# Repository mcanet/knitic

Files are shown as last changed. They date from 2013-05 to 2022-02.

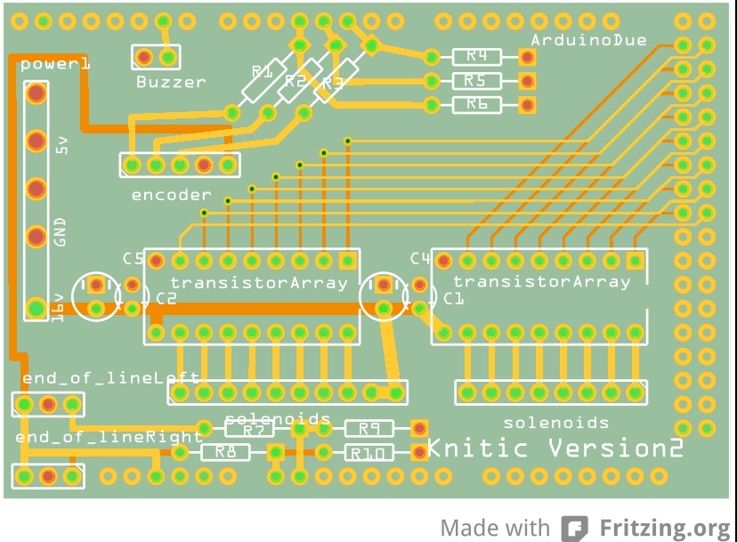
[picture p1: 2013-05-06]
pcb_design/ArduinoDue/KniticV2_+CompactPCB2Res_pcb.jpg

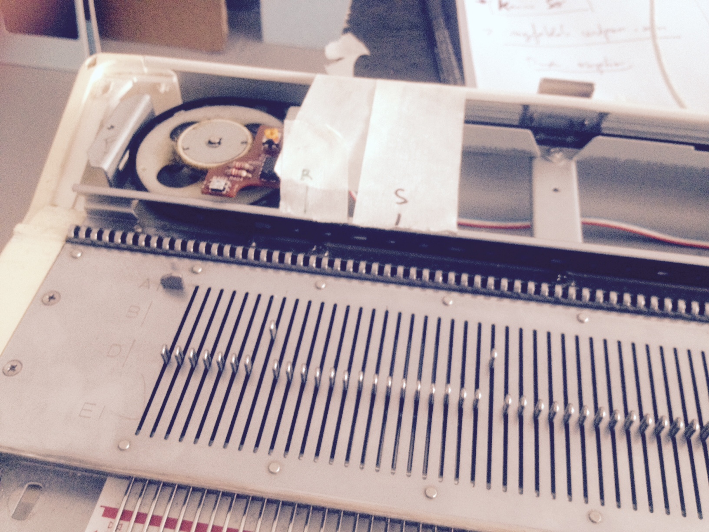
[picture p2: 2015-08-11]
arduino_code/test_incase_error/test_encoder_beltshift/regular.jpg

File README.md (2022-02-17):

Knitic
======

This software is part of the first open hardware knitting machine project, at the moment based on old electronic Brother knitting machines. 

Here we are testing with KH930, KH940, but we will work with any Digital Brother Knitting machine. 

We have developed in an artist residency at Marginalia+Lab in Belo Horizonte (Brazil) and Constant(Belgium). 
There is more information on the project website: http://knitic.com

Authors: Varvara Guljajeva(http://varvarag.info) and Mar Canet (http://mcanet.info). We are a couple of new media artist that we like to build our own tools.

We have publish some articles about this topic:
- Knitic - The Revolution of Soft Digital Fabrication. DH 2013: 497-499 [http://dh2013.unl.edu/abstracts/ab-173.html]

The project copyright with GNU-GPL: http://es.wikipedia.org/wiki/GNU_General_Public_License

Any questions please send to: mar.canet@gmail.com

> THIS MATERIAL IS DISTRIBUTED AS IS WITH NO GUARANTEE OF FUNCTIONALITY OR RELEVANCE TO THIRD PARTY PROJECTS - THE DEVELOPERS ARE THUS NOT TO BE HELD RESPONSIBLE FOR PERSONAL INJURIES, HARDWARE, FINANCIAL, OR ANY OTHER LOSSES AND IN GENERAL FOR ANY MISFORTUNATE EVENT CAUSED BY THE DESCRIBED SOFTWARE/HARDWARE OR IN THE PROCESS OF ATTEMPTING TO IMPLEMENT IT. IF YOU DON'T AGREE WITH THE AFOREMENTIONED YOUR ARE NOT ALLOWED TO USE THE MATERIAL PROVIDED HEREIN

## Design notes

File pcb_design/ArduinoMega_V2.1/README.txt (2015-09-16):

README Knitic v2.1 - 09/2015
Fablab Wellington
Zoilo ABAD

Changes :
-Eagle files
-improvement with smd component
-selectable 5V or 3.3V
-inboard resistor for optoswitch

-add a adapter board for KH-970 connector

choice the right resistor for the optoswitch you have and the voltage you have.

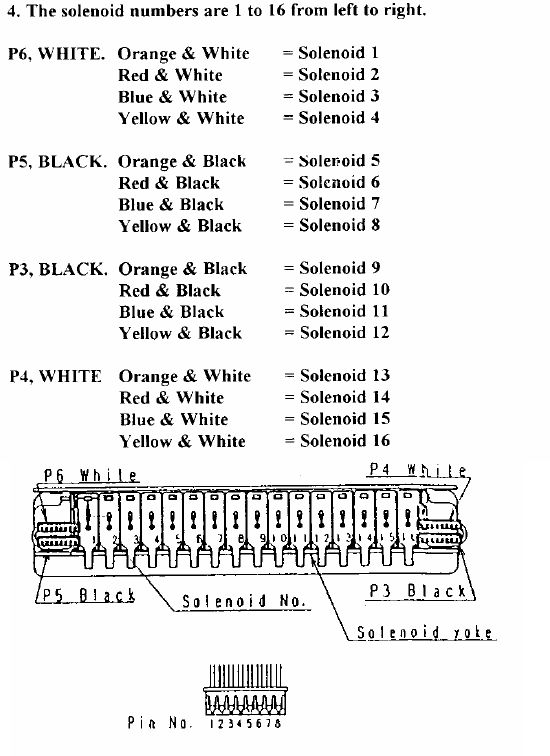
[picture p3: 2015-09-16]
pcb_design/ArduinoMega_V2.1/solenoids.png

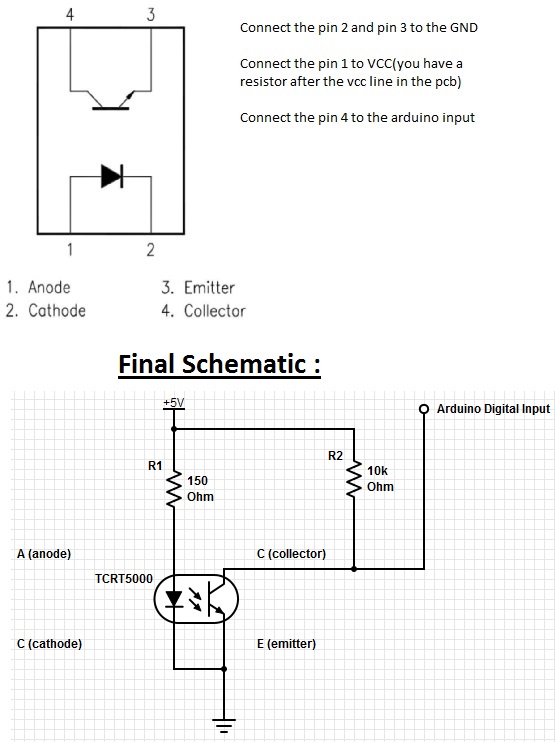
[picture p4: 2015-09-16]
pcb_design/ArduinoMega_V2.1/Opto switch.jpg

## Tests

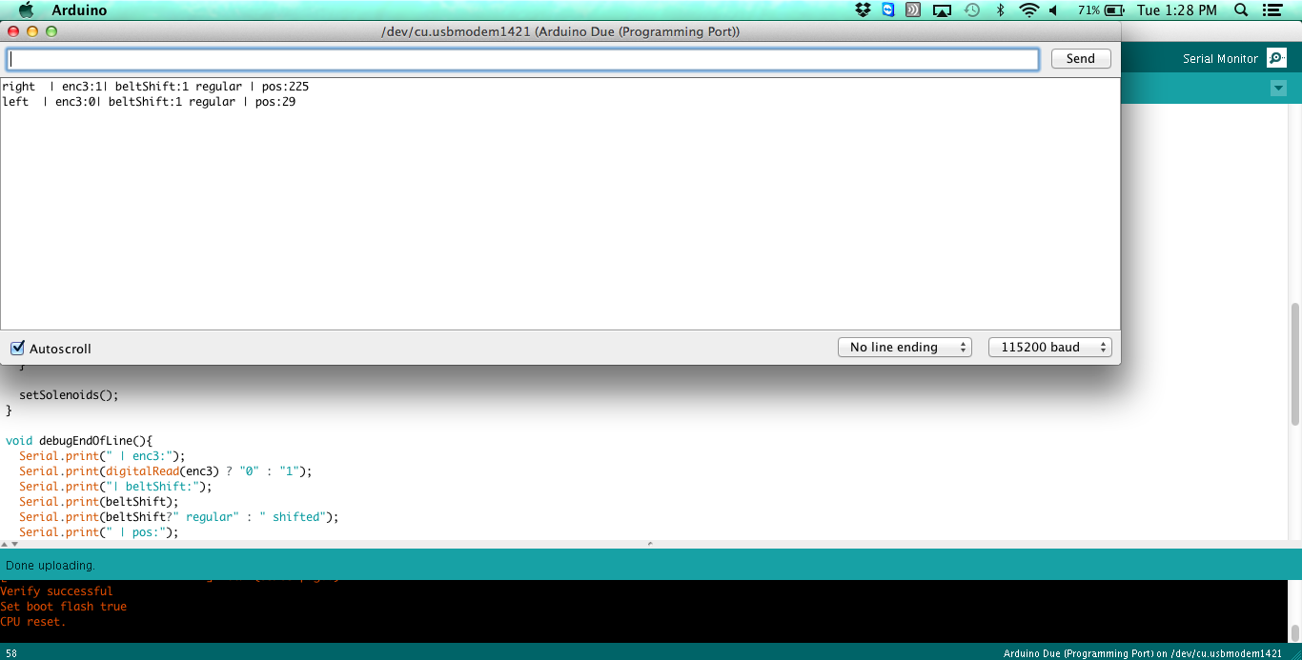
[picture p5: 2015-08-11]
arduino_code/test_incase_error/test_encoder_beltshift/console_showing_belt_status.png

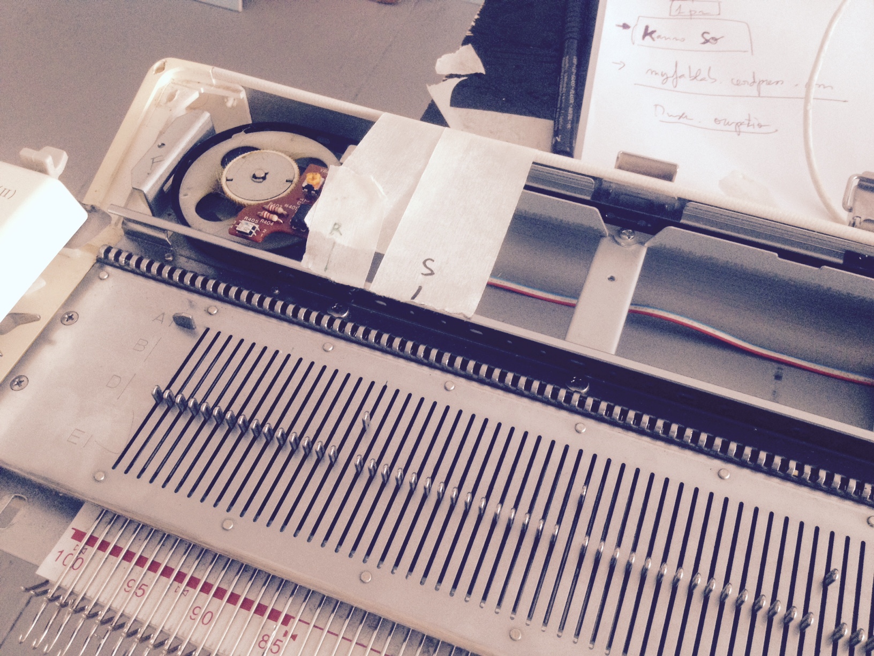
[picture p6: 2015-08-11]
arduino_code/test_incase_error/test_encoder_beltshift/shifted.jpg

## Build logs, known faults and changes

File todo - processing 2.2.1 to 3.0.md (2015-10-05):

todo

- sdrop doesn't work
- icon of standalone application doesn't work
- shape of parametric sweater doesn't work
- open and save dialogue close the main frame, know issue without solution yet (https://github.com/processing/processing/issues/3831)

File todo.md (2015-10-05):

todo

- fix "error in pixel" -> OK
- fix corrupt data that stop the arduino -> OK
- check solenoid glitch -> close to be OK, much better with the fork of kinasmith
- check beltshift
- begin message to less error -> ok
- release solenoid when no connection -> ok
- fast read write on arduino
- go to processing 3.0 (maybe delete the sdrop)

ayab
- initialisation
- active needle or not
- offset
- reset at the EOL

// Machine is initialized when left hall sensor is passed in Right direction
		if( Right == m_direction && Left == m_hallActive )
		{
			m_opState = s_ready;
			m_solenoids.setSolenoids(0xFFFF);
			return;
		}
		
if( (m_pixelToSet >= m_startNeedle-END_OF_LINE_OFFSET_L)
				&& (m_pixelToSet <= m_stopNeedle+END_OF_LINE_OFFSET_R)) // TODO ADD OFFSET
		{	// When inside the active needles
		}
		else
		{	// Outside of the active needles

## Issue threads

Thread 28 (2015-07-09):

Mac OS X not working

bamundy, 2015-07-09:
I'm using a MacBookPro 2.7GHz Intel Core i7 8Gb 1333 MHz DDR3 RAM using OS X 10.9.5. with an Arduino compatible OSEPP Uno R3 Plus.

I've downloaded the Arduino Application and am able to connect and power the board.

I've downloaded the latest Knitic software version from Github, yet every time I've attempted to open/install the software it gives the following error message . . . Please help.

Jo Ann Mundy

Arduino: 1.6.5 (Mac OS X), Board: "Arduino Uno"

protoAppKnitic_p5:11: error: variable or field 'serialEvent' declared void
protoAppKnitic_p5:11: error: expected ')' before 'p'
protoAppKnitic_p5:17: error: variable or field 'dropEvent' declared void
protoAppKnitic_p5:17: error: 'DropEvent' was not declared in this scope
protoAppKnitic_p5:8: error: 'import' does not name a type
protoAppKnitic_p5:9: error: 'import' does not name a type
protoAppKnitic_p5:10: error: 'import' does not name a type
protoAppKnitic_p5:11: error: 'import' does not name a type
protoAppKnitic_p5:12: error: 'import' does not name a type
protoAppKnitic_p5:13: error: 'import' does not name a type
protoAppKnitic_p5:17: error: 'ControlP5' does not name a type
protoAppKnitic_p5:18: error: 'Serial' does not name a type
protoAppKnitic_p5:19: error: 'PImage' does not name a type
protoAppKnitic_p5:20: error: 'PImage' does not name a type
protoAppKnitic_p5:21: error: 'PFont' does not name a type
protoAppKnitic_p5:29: error: expected unqualified-id before '[' token
protoAppKnitic_p5:39: error: expected unqualified-id before '[' token
protoAppKnitic_p5:40: error: expected unqualified-id before '[' token
protoAppKnitic_p5:70: error: storage size of 'bitRegister16SolenoidTemp' isn't known
protoAppKnitic_p5:71: error: 'SDrop' does not name a type
protoAppKnitic_p5:77: error: expected unqualified-id before '[' token
protoAppKnitic_p5:78: error: expected unqualified-id before '[' token
protoAppKnitic_p5:80: error: 'DropdownList' does not name a type
protoAppKnitic_p5:81: error: 'DropdownList' does not name a type
protoAppKnitic_p5:82: error: 'JSONObject' does not name a type
protoAppKnitic_p5:83: error: 'parametricSweater' does not name a type
protoAppKnitic_p5:84: error: 'controlP5' does not name a type
protoAppKnitic_p5:85: error: 'controlP5' does not name a type
protoAppKnitic_p5:86: error: 'controlP5' does not name a type
protoAppKnitic_p5:87: error: 'controlP5' does not name a type
protoAppKnitic_p5:88: error: 'controlP5' does not name a type
protoAppKnitic_p5:89: error: 'PFont' does not name a type
protoAppKnitic_p5:90: error: 'Boolean' does not name a type
protoAppKnitic_p5:92: error: 'controlP5' does not name a type
protoAppKnitic_p5:93: error: 'controlP5' does not name a type
protoAppKnitic_p5:94: error: 'controlP5' does not name a type
protoAppKnitic_p5:95: error: 'controlP5' does not name a type
protoAppKnitic_p5:96: error: 'controlP5' does not name a type
protoAppKnitic_p5.pde: In function 'void setup()':
protoAppKnitic_p5:100: error: 'P2D' was not declared in this scope
protoAppKnitic_p5:100: error: 'size' was not declared in this scope
protoAppKnitic_p5:101: error: 'noSmooth' was not declared in this scope
protoAppKnitic_p5:103: error: 'frame' was not declared in this scope
protoAppKnitic_p5:103: error: 'null' was not declared in this scope
protoAppKnitic_p5:106: error: 'ImageIcon' was not declared in this scope
protoAppKnitic_p5:106: error: expected ';' before 'titlebaricon'
protoAppKnitic_p5:107: error: 'titlebaricon' was not declared in this scope
protoAppKnitic_p5:110: error: 'setupSweater' was not declared in this scope
protoAppKnitic_p5:112: error: 'setupSettings' was not declared in this scope
protoAppKnitic_p5:113: error: 'addButtonsInSetup' was not declared in this scope
protoAppKnitic_p5:114: error: 'setupSerialConnection' was not declared in this scope
protoAppKnitic_p5:115: error: 'kniticLogo' was not declared in this scope
protoAppKnitic_p5:115: error: 'loadImage' was not declared in this scope
protoAppKnitic_p5:116: error: 'laurentFont' was not declared in this scope
protoAppKnitic_p5:116: error: 'loadFont' was not declared in this scope
protoAppKnitic_p5:117: error: 'currentPixels' was not declared in this scope
protoAppKnitic_p5:118: error: '_16SolenoidsAr' was not declared in this scope
protoAppKnitic_p5:121: error: 'setupAudio' was not declared in this scope
protoAppKnitic_p5:141: error: 'drop' was not declared in this scope
protoAppKnitic_p5:141: error: expected type-specifier before 'SDrop'
protoAppKnitic_p5:141: error: expected ';' before 'SDrop'
protoAppKnitic_p5:142: error: 'pixelSend' was not declared in this scope
protoAppKnitic_p5:143: error: 'pixelReceived' was not declared in this scope
protoAppKnitic_p5:148: error: 'createSweater' was not declared in this scope
protoAppKnitic_p5:149: error: 'showHideFeaturesOpenKnit' was not declared in this scope
protoAppKnitic_p5.pde: In function 'void draw()':
protoAppKnitic_p5:156: error: 'frame' was not declared in this scope
protoAppKnitic_p5:156: error: 'Integer' was not declared in this scope
In file included from protoAppKnitic_p5.pde:8:0:
protoAppKnitic_p5:156: error: 'frameRate' was not declared in this scope
/Applications/Arduino.app/Contents/Java/hardware/arduino/avr/cores/arduino/Arduino.h:88:24: note: in definition of macro 'round'
 #define round(x)     ((x)>=0?(long)((x)+0.5):(long)((x)-0.5))
                        ^
protoAppKnitic_p5:157: error: 'background' was not declared in this scope
protoAppKnitic_p5:158: error: 'display' was not declared in this scope
protoAppKnitic_p5:159: error: 'drawPatternGrid' was not declared in this scope
protoAppKnitic_p5:162: error: 'drawPattern' was not declared in this scope
protoAppKnitic_p5:163: error: 'drawAndSetSelectedGrid' was not declared in this scope
protoAppKnitic_p5:166: error: 'showCursorPosition' was not declared in this scope
protoAppKnitic_p5:167: error: 'updateEditPixels' was not declared in this scope
protoAppKnitic_p5:169: error: 'drawReceivedPixelsVsSend' was not declared in this scope
protoAppKnitic_p5:172: error: 'machineList' was not declared in this scope
protoAppKnitic_p5:172: error: 'drawOpenKnit' was not declared in this scope
protoAppKnitic_p5:174: error: 'createSweater' was not declared in this scope
protoAppKnitic_p5:175: error: 'drawSweater' was not declared in this scope
protoAppKnitic_p5.pde: At global scope:
protoAppKnitic_p5:181: error: variable or field 'serialEvent' declared void
protoAppKnitic_p5:181: error: expected ')' before 'p'
protoAppKnitic_p5.pde: In function 'void brain()':
protoAppKnitic_p5:194: error: 'startRightSide' was not declared in this scope
protoAppKnitic_p5:195: error: 'startLeftSide' was not declared in this scope
protoAppKnitic_p5:209: error: 'done' was not declared in this scope
protoAppKnitic_p5:211: error: 'Integer' was not declared in this scope
protoAppKnitic_p5:211: error: 'println' was not declared in this scope
protoAppKnitic_p5:213: error: 'sendtoKnittingMachine' was not declared in this scope
protoAppKnitic_p5:226: error: 'done' was not declared in this scope
protoAppKnitic_p5:228: error: 'Integer' was not declared in this scope
protoAppKnitic_p5:228: error: 'println' was not declared in this scope
protoAppKnitic_p5:230: error: 'sendtoKnittingMachine' was not declared in this scope
protoAppKnitic_p5.pde: In function 'int getReadPixelsFromPosition(int)':
protoAppKnitic_p5:244: error: 'pixelArray' was not declared in this scope
protoAppKnitic_p5:246: error: expected type-specifier before 'Exception'
protoAppKnitic_p5:246: error: exception handling disabled, use -fexceptions to enable
protoAppKnitic_p5:246: error: expected ')' before 'e'
protoAppKnitic_p5:246: error: expected '{' before 'e'
protoAppKnitic_p5:246: error: 'e' was not declared in this scope
protoAppKnitic_p5:246: error: expected ';' before ')' token
protoAppKnitic_p5.pde: In function 'void setOFFSolenoids()':
protoAppKnitic_p5:256: error: '_16SolenoidsAr' was not declared in this scope
protoAppKnitic_p5.pde: At global scope:
protoAppKnitic_p5:274: error: variable or field 'dropEvent' declared void
protoAppKnitic_p5:274: error: 'DropEvent' was not declared in this scope
variable or field 'serialEvent' declared void

  This report would have more information with
  "Show verbose output during compilation"
  enabled in File > Preferences.

thiagohersan, 2015-07-09:
Hi. I'm just guessing, but it looks like you're trying to run the Processing code on the Arduino...

The stuff in the protoAppKnitic_p5 directory is an app for Processing. The Arduino code is in the directory called arduino_code/openKnitting_handMadepcb_v0_1.

bamundy, 2015-07-09:
Thank you!!

jam

Sent from my iPhone

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

Closed 2015-09-21.

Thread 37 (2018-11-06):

knitic page seems broken

Wouter1, 2018-11-06:
http://www.knitic.com/ seems broken

I only get a blank page (tested both on firefox and safari)

I was looking for info on how to use and attach this, why you need the PCB's provided here, some examples on what it can do, the supported hardware (I only see KH930 and KH940) etc. All this info seems not available here.

infosisio, 2020-06-24:
Still broken :/

Kejkrt, 2021-01-04:
Arduino+shield --- [https://ayab-knitting.com/ayab-shield/](url)

Closed 2024-12-04.

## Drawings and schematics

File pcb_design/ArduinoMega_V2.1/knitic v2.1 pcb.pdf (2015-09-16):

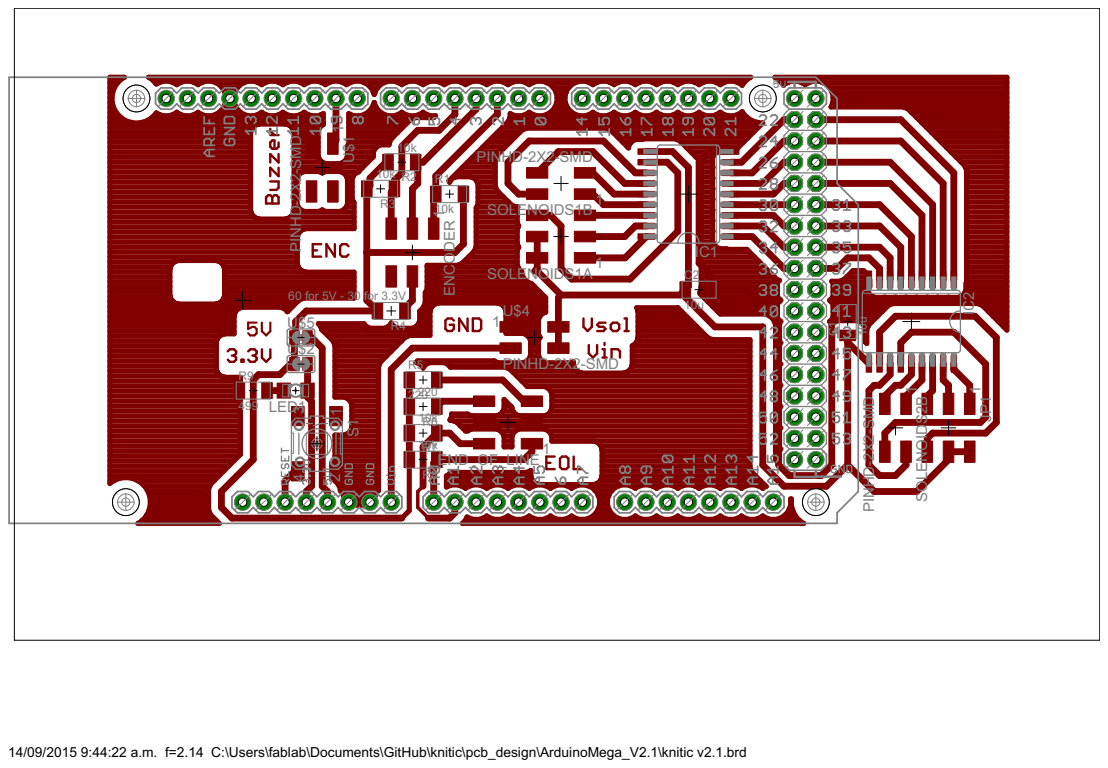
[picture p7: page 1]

14/09/2015 9:44:22 a.m. f=2.14 C:\Users\fablab\Documents\GitHub\knitic\pcb_design\ArduinoMega_V2.1\knitic v2.1.brd

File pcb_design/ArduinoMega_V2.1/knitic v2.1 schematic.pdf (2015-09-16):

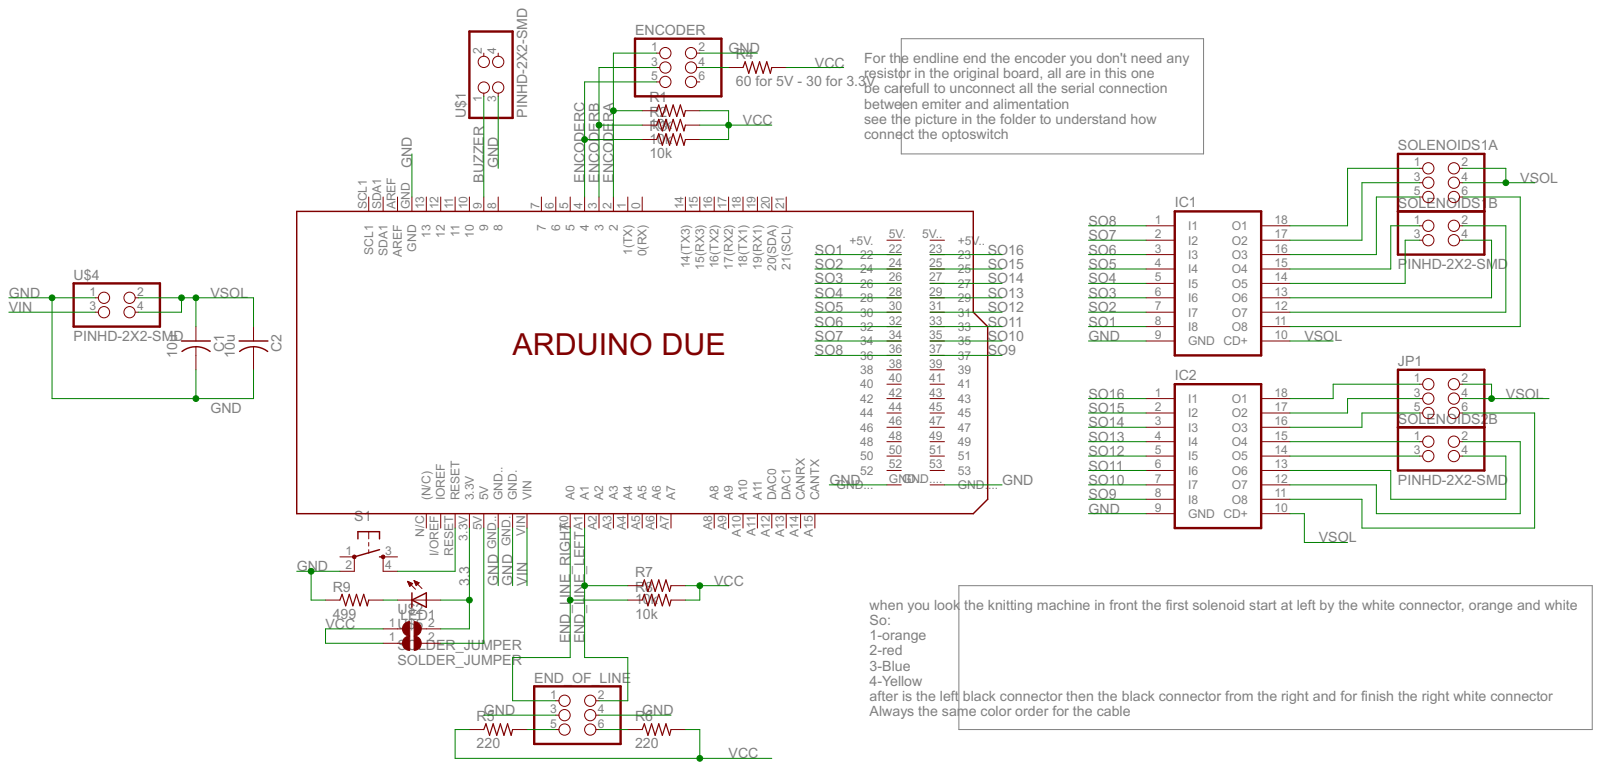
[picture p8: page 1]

3 4
5 6

For the endline end the encoder you don't need any
resistor in the original board, all are in this one
be carefull to unconnect all the serial connection
between emiter and alimentation
see the picture in the folder to understand how
connect the optoswitch

SCL1 SCL1 SDA1 SDA1 AREF AREF GND GND

VIN GND. GND. GND.. GND.. 5V

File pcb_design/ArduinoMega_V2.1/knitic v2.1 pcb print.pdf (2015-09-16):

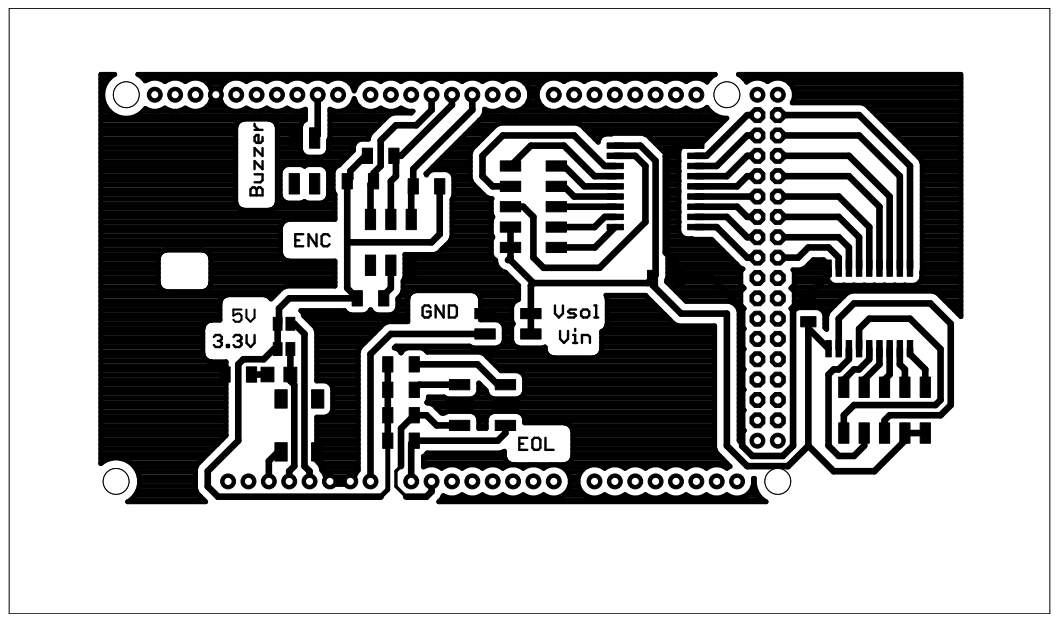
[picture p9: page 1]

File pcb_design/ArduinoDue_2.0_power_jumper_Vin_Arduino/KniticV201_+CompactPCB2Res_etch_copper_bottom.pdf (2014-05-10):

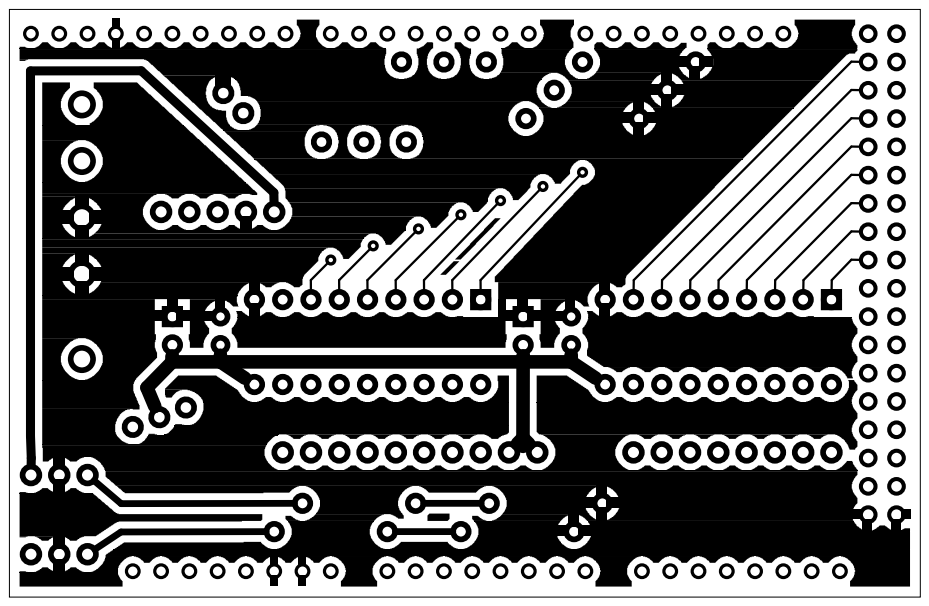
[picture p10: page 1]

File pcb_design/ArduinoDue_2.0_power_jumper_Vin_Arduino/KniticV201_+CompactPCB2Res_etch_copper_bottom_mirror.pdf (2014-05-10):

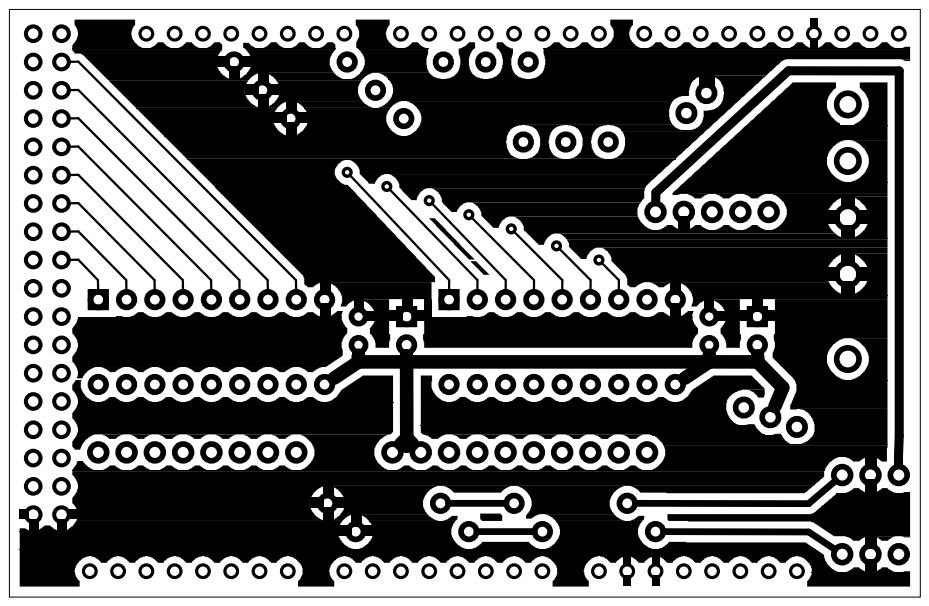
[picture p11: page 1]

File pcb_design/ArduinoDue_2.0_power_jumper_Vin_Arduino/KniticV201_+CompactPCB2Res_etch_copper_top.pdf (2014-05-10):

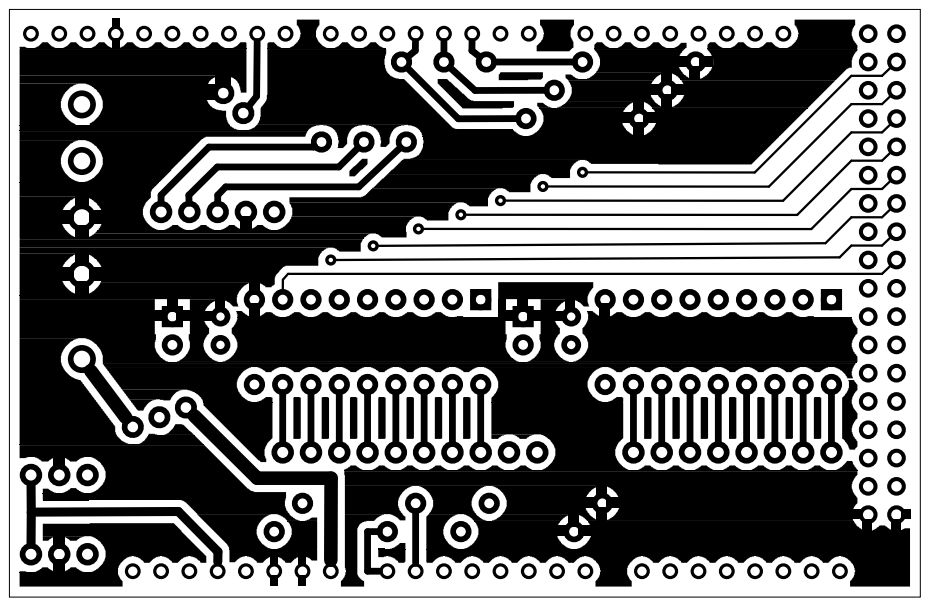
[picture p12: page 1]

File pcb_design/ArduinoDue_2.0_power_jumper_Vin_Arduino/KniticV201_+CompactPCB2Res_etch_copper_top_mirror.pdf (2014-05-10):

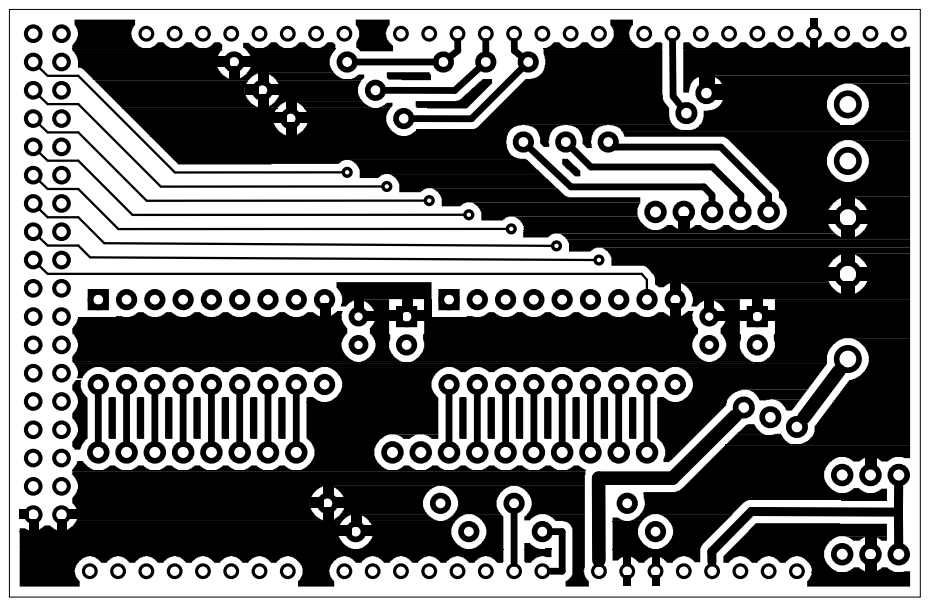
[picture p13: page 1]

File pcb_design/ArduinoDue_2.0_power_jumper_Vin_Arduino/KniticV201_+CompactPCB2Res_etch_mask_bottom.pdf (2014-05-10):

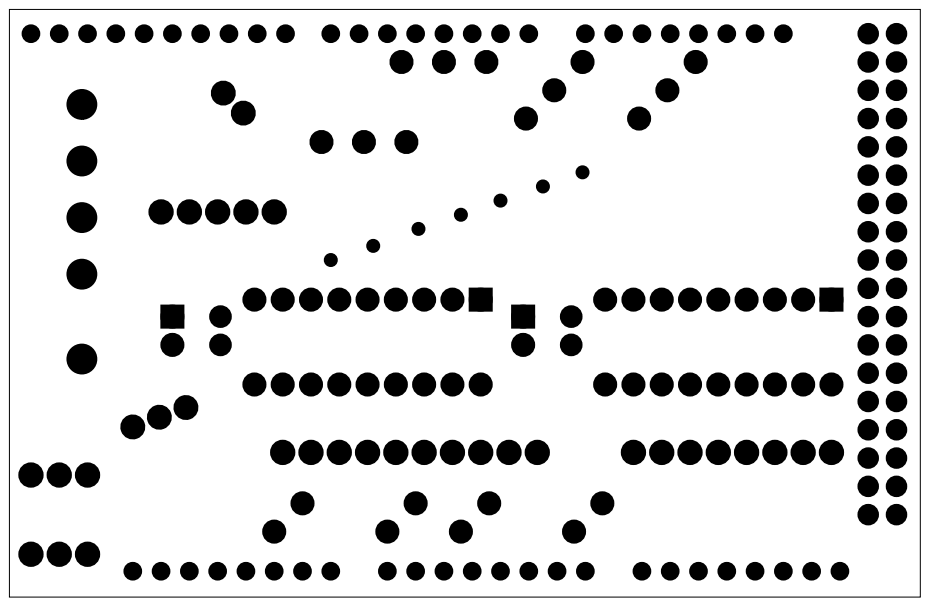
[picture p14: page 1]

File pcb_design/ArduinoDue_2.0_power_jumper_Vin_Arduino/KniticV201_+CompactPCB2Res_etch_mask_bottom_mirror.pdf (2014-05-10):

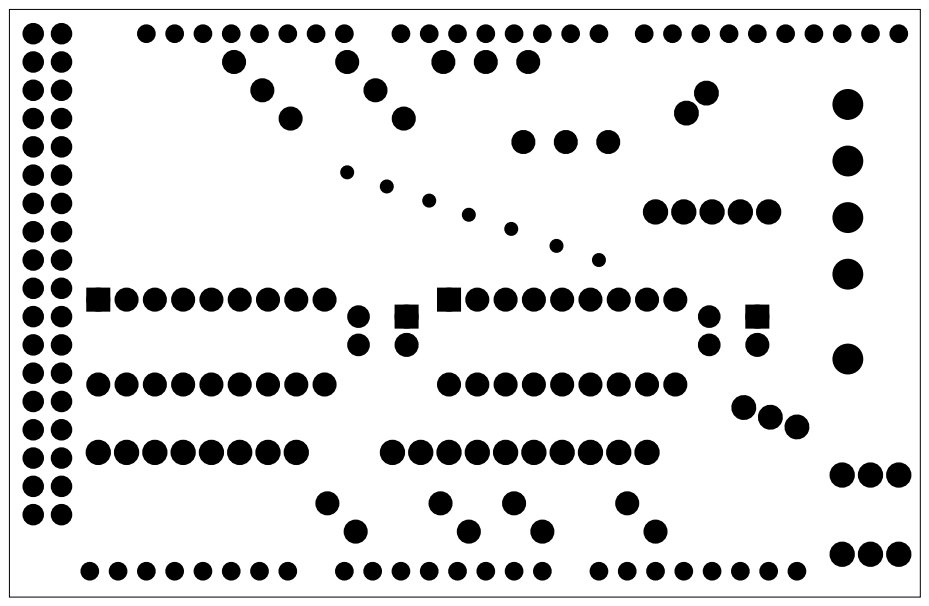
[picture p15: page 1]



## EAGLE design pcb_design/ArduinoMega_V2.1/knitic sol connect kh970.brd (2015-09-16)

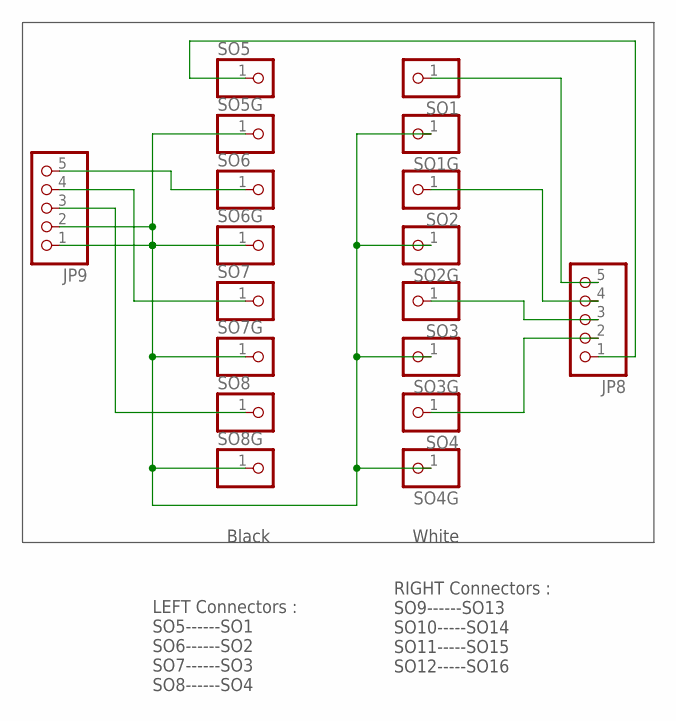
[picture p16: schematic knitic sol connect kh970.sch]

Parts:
JP8, JP9: PINHD-1X5; 1X05
SO1, SO1G, SO2, SO2G, SO3, SO3G, SO4, SO4G, SO5, SO5G, SO6, SO6G, SO7, SO7G, SO8, SO8G: PINHD-1X1; 1X01

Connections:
unnamed: JP9.3, SO8.1
unnamed: JP9.4, SO7.1
unnamed: JP8.1, SO5.1
unnamed: JP8.5, SO1.1
unnamed: JP8.4, SO2.1
unnamed: JP8.3, SO3.1
unnamed: JP8.2, SO4.1
unnamed: JP9.1, JP9.2, SO1G.1, SO2G.1, SO3G.1, SO4G.1, SO5G.1, SO6G.1, SO7G.1, SO8G.1
SO6G: JP9.5, SO6.1

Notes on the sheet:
White
Black
LEFT Connectors : SO5------SO1 SO6------SO2 SO7------SO3 SO8------SO4
RIGHT Connectors : SO9------SO13 SO10-----SO14 SO11-----SO15 SO12-----SO16

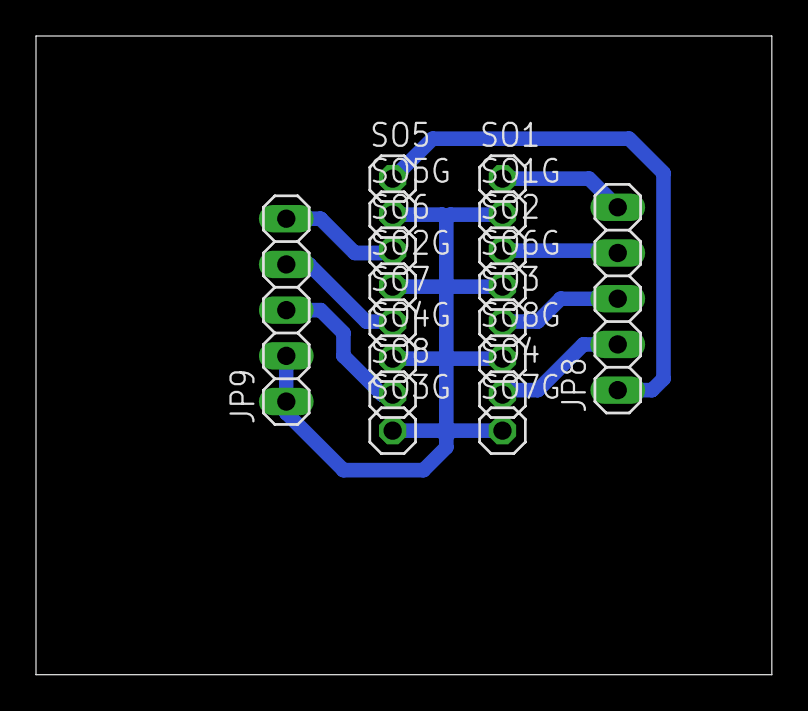
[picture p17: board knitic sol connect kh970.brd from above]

Board: 2 copper layers, 40.9 x 35.5 mm, 18 parts (0 on the bottom side), 9 nets.

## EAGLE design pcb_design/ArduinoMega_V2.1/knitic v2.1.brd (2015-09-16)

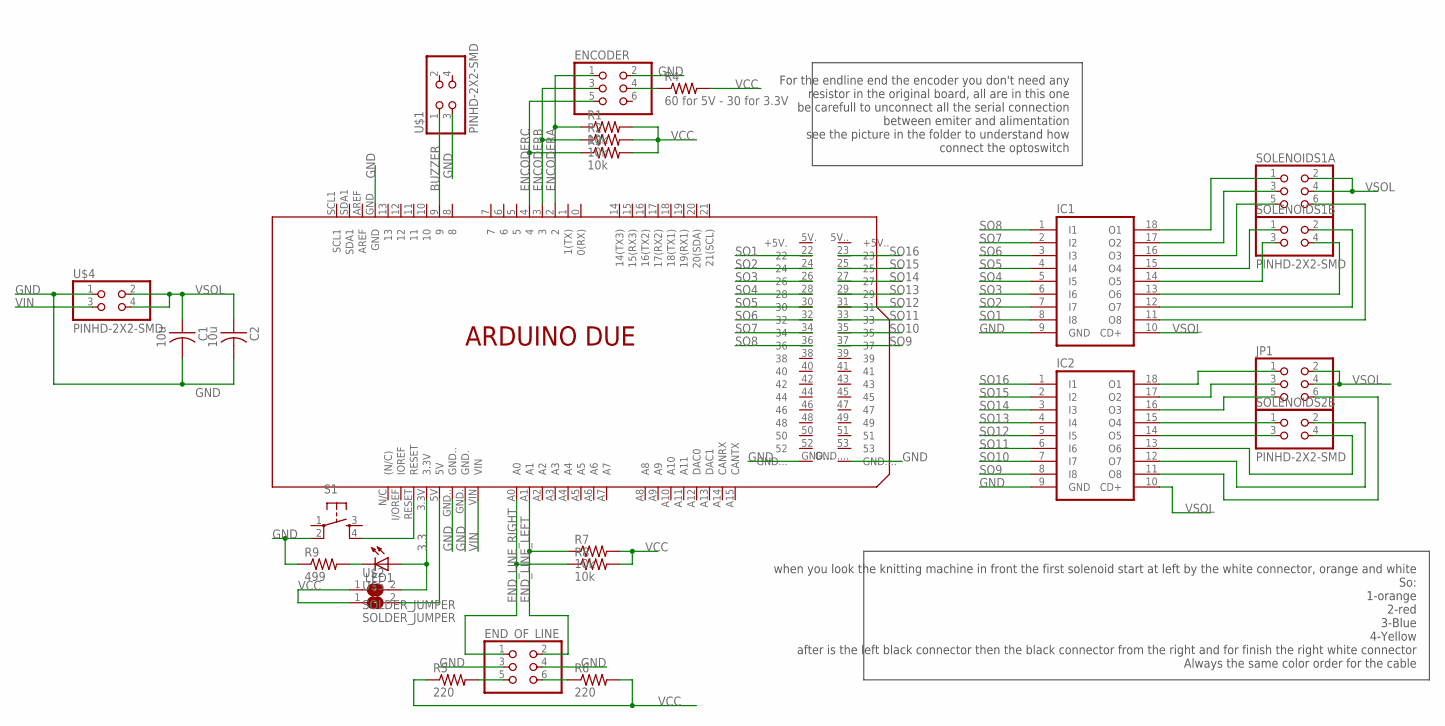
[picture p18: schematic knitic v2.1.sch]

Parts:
C1, C2: 10u; C1206FAB
ENCODER: PINHD-2X3-SMD; 2X03SMD
END_OF_LINE: PINHD-2X3-SMD; 2X03SMD
IC1, IC2: ULN2803ASO; SO18W
JP1: PINHD-2X3-SMD; 2X03SMD
LED1: LEDSMT1206; 1206
PCB1: ARDUINO_DUE_MIN
R1, R2, R3, R7, R8: 10k; R1206FAB
R4: 60 for 5V - 30 for 3.3V; R1206FAB
R5, R6: 220; R1206FAB
R9: 499; R1206FAB
S1: 6MM_SWITCH6MM_SWITCH; 6MM_SWITCH
SOLENOIDS1A: PINHD-2X3-SMD; 2X03SMD
SOLENOIDS1B, SOLENOIDS2B: PINHD-2X2-SMD; 2X02SMD
U$1, U$4: PINHD-2X2-SMD; 2X02SMD
U$2, U$5: SOLDER_JUMPER; SJFAB

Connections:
3.3: LED1.A, PCB1.3.3V, U$2.2
BUZZER: PCB1.9, U$1.1
ENCODERA: ENCODER.1, PCB1.2, R1.1
ENCODERB: ENCODER.3, PCB1.3, R2.1
ENCODERC: ENCODER.5, PCB1.4, R3.1
END_LINE_LEFT: END_OF_LINE.2, PCB1.A1, R7.1
END_LINE_RIGHT: END_OF_LINE.1, PCB1.A0, R8.1
GND: C1.2, C2.2, ENCODER.2, END_OF_LINE.3, END_OF_LINE.4, IC1.9 (GND), IC2.9 (GND), PCB1.GND, PCB1.GND., PCB1.GND.., R9.1, S1.2 (P1), U$1.3, U$4.1
unnamed: ENCODER.4, R4.1
unnamed: END_OF_LINE.5, R5.2
unnamed: PCB1.RESET, S1.4 (S1)
unnamed: IC1.18 (O1), SOLENOIDS1A.1
unnamed: END_OF_LINE.6, R6.1
unnamed: LED1.C, R9.2
unnamed: IC1.17 (O2), SOLENOIDS1A.3
unnamed: IC1.16 (O3), SOLENOIDS1A.5
unnamed: IC1.15 (O4), SOLENOIDS1B.1
unnamed: IC1.14 (O5), SOLENOIDS1B.3
unnamed: IC1.13 (O6), SOLENOIDS1B.4
unnamed: IC1.12 (O7), SOLENOIDS1B.2
unnamed: IC1.11 (O8), SOLENOIDS1A.6
unnamed: IC2.18 (O1), JP1.1
unnamed: IC2.12 (O7), SOLENOIDS2B.2
unnamed: IC2.17 (O2), JP1.3
unnamed: IC2.16 (O3), JP1.5
unnamed: IC2.13 (O6), SOLENOIDS2B.4
unnamed: IC2.15 (O4), SOLENOIDS2B.1
unnamed: IC2.11 (O8), JP1.6
unnamed: PCB1.5V, U$5.2
unnamed: IC2.14 (O5), SOLENOIDS2B.3
SO1: IC1.8 (I8), PCB1.22
SO2: IC1.7 (I7), PCB1.24
SO3: IC1.6 (I6), PCB1.26
SO4: IC1.5 (I5), PCB1.28
SO5: IC1.4 (I4), PCB1.30
SO6: IC1.3 (I3), PCB1.32
SO7: IC1.2 (I2), PCB1.34
SO8: IC1.1 (I1), PCB1.36
SO9: IC2.8 (I8), PCB1.37
SO10: IC2.7 (I7), PCB1.35
SO11: IC2.6 (I6), PCB1.33
SO12: IC2.5 (I5), PCB1.31
SO13: IC2.4 (I4), PCB1.29
SO14: IC2.3 (I3), PCB1.27
SO15: IC2.2 (I2), PCB1.25
SO16: IC2.1 (I1), PCB1.23
VCC: R1.2, R2.2, R3.2, R4.2, R5.1, R6.2, R7.2, R8.2, U$2.1, U$5.1
VIN: PCB1.VIN, U$4.3
VSOL: C1.1, C2.1, IC1.10 (CD+), IC2.10 (CD+), JP1.2, JP1.4, SOLENOIDS1A.2, SOLENOIDS1A.4, U$4.2, U$4.4

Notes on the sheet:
when you look the knitting machine in front the first solenoid start at left by the white connector, orange and white So: 1-orange 2-red 3-Blue 4-Yellow after is the left black connector then the black connector from the right and for finish the right white connector Always the same color order for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
For the endline end the encoder you don't need any resistor in the original board, all are in this one be carefull to unconnect all the serial connection between emiter and alimentation see the picture in the folder to understand how connect the optoswitch

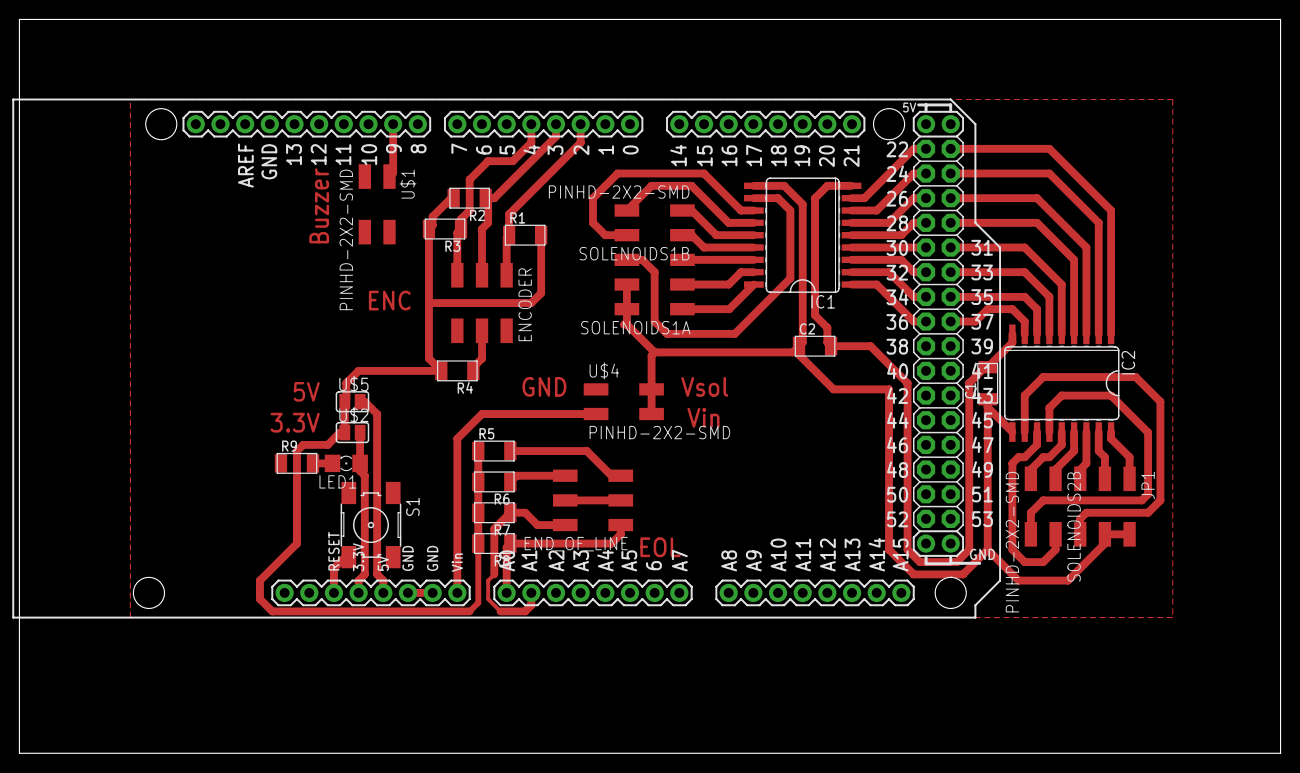
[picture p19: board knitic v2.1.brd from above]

Board: 2 copper layers, 129.8 x 75.6 mm, 26 parts (0 on the bottom side), 49 nets.

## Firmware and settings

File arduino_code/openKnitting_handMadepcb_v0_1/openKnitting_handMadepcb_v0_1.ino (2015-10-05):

/*
 *
 * KNITIC: OPEN KNITTING MACHINE
 * @Description: Code for open source machine
 * @Authors: Mar Canet <mar.canet@gmail.com> & Varvara Guljajeva <varvarag@gmail.com> 
 * @Contributors: github.com/drachezoil 
 * @Versions:0.1v 
 *
 This program is free software: you can redistribute it and/or modify
 it under the terms of the GNU General Public License as published by
 the Free Software Foundation, either version 3 of the License, or
 (at your option) any later version.
 */

#define arduinoTypeDUE "due"
//#define arduinoTypeUNO "uno"

//#define machineType970 "970"
#define machineType940 "940"

#define totalArrayFromSelenoids 16
// Important! This four values need to be calibrate in each machine
// Use code at: "arduino code/test_incase_error/test_endLine_calibrate" 
// When you execute you will find values in the arduino terminal and change the right values for your machine
#define FILTER_VALUE_LEFT_MIN 100
#define FILTER_VALUE_RIGHT_MIN 100
#define FILTER_VALUE_LEFT_MAX 515
#define FILTER_VALUE_RIGHT_MAX 515

#define END_LEFT       255
#define END_RIGHT      0
// important to setup, different for each type of machine
#ifdef machineType970
  #define START_OFFSET_L 42
  #define START_OFFSET_R 22
#endif
#ifdef machineType940
  #define START_OFFSET_L 40
  #define START_OFFSET_R 16
#endif

#define END_OF_LINE_OFFSET_L 32
#define END_OF_LINE_OFFSET_R 12
//#define cariageTypeL 'L'
#define cariageTypeK 'K'

#define attachInterrupEncoders interrupEncoders

#include "defined_knitic.h"
#include "knitic.h"

//---------------------------------------------------------------------------------
//---------------------------------------------------------------------------------
// Class declaration
encoders myEncoders;
endLines myEndlines;
solenoids mysolenoids;
soundAlerts mySoundAlerts;
communication myCommunicator;

void setup()
{ 
  Serial.begin(115200);
  mySoundAlerts.setup();
  myEncoders.setup();
  //myEndlines.setup();
  myEndlines.setPosition(&myEncoders);
  mysolenoids.setup(&myEndlines,&myEncoders);
  myCommunicator.setup(&myEncoders,&myEndlines,&mysolenoids);
  myCommunicator._status = "o";
#ifdef attachInterrupEncoders
  attachInterrupt(digitalPinToInterrupt(encoder0PinA), encoderChange, CHANGE);
  //attachInterrupt(digitalPinToInterrupt(encoder0PinA), encoderChange, RISING);
#endif
} 

void loop() {
  // Receive solenoids from computer
  serialEvent();
  // Get data from sensors and send to computer in case solenoids not move
#ifndef attachInterrupEncoders
  myEncoders.loopNormal();
  myEndlines.loop();
  mysolenoids.loop();
#endif

  myCommunicator.sendSerialToComputer(); 
}

void serialEvent(){
  myCommunicator.receiveAllLine();
}

#ifdef attachInterrupEncoders
void encoderChange(){
  myEncoders.loopAttachInterrupt();
  myEndlines.loop();
  mysolenoids.loop();
}
#endif

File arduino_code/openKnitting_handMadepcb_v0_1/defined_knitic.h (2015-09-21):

#ifndef DEFINED_KNITIC_H_
#define DEFINED_KNITIC_H_

#ifdef arduinoTypeUNO
    #define encoder0PinA 2
    #define encoder0PinB 3
    #define encoder0PinC 4
#endif
#ifdef arduinoTypeDUE
    #define encoder0PinA 2
    #define encoder0PinB 3
    #define encoder0PinC 4
    #define piezoPin     9
    #define endLineLeftAPin A1
    #define endLineRightAPin A0
#endif

#endif

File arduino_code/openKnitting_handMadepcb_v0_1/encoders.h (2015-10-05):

#ifndef ENCODERS_H_
#define ENCODERS_H_
//---------------------------------------------------------------------------------
//---------------------------------------------------------------------------------
// table created to get combinations
/*
table encoder position an values id
 OFF_ON  = 0+3 = 3
 ON_OFF  = 1+5 = 6
 ON_ON   = 1+3 = 4
 OFF_OFF = 0+5 = 5 
 */

#define OFF_ON 3
#define ON_OFF 6
#define ON_ON 4
#define OFF_OFF 5

#include "arduino.h"
#include "defined_knitic.h"

class encoders{
private:
  short directionEncoders;
  short lastDirectionEncoders;
  int encoder4Pos;
  int lastencoder4Pos;
  //boolean last_8segmentEncoder;
public:
  int encoder1Pos; 
  int lastencoder1Pos;
  int stitch;
  int lastStitch;
  int headDirection;
  boolean _8segmentEncoder;
  
  encoders(){
  }
  ~encoders(){
  }

  void setup(){
    pinMode(encoder0PinA,INPUT);
    pinMode(encoder0PinB,INPUT);
    pinMode(encoder0PinC,INPUT);
    headDirection = 0;
    encoder1Pos = -2000;
    lastencoder1Pos = -1;
    encoder4Pos = 0;
    lastencoder4Pos = -1;
    lastDirectionEncoders = 0;
    lastStitch=0;
    stitch=-1;
    _8segmentEncoder = 0;
    //last_8segmentEncoder = 0;
  }

  
  // Use call from normal loop
  void loopNormal(){
    calculateDirection();
    if(lastDirectionEncoders!=directionEncoders){
      if((lastDirectionEncoders==OFF_OFF && directionEncoders==OFF_OFF)  || 
        (lastDirectionEncoders==OFF_OFF && directionEncoders==ON_OFF) || 
        (lastDirectionEncoders==ON_OFF && directionEncoders==ON_ON)   || 
        (lastDirectionEncoders==ON_ON && directionEncoders==OFF_ON)   || 
        (lastDirectionEncoders==OFF_ON && directionEncoders==OFF_OFF)){
        headDirection =-1;
        if( encoder1Pos==-2000){ 
          encoder4Pos = 1020;//255 * 4
          encoder1Pos = 255;
        }
        encoder4Pos-=1;
        if(encoder4Pos<0){
          encoder4Pos=0;
        }
      }
      else if((lastDirectionEncoders==OFF_ON && directionEncoders==ON_ON)  || 
        (lastDirectionEncoders==ON_ON && directionEncoders==ON_ON)   || 
        (lastDirectionEncoders==ON_ON && directionEncoders==ON_OFF)  || 
        (lastDirectionEncoders==ON_OFF && directionEncoders==OFF_OFF)|| 
        (lastDirectionEncoders==OFF_OFF && directionEncoders==OFF_ON)){
        headDirection =+1;
        if( encoder1Pos==-2000){ 
          encoder4Pos = 0;
          encoder1Pos = 0;
        }
        encoder4Pos+=1;
        if(encoder4Pos>1020){//255 * 4
          encoder4Pos=1020;
        }
      }
    }
    
    if( encoder4Pos !=0 ){ 
      encoder1Pos = encoder4Pos/4;
      stitch = (encoder1Pos)-28; 
    }
    else{
      encoder1Pos = 0;
      stitch = -28;
    }
  }
  
  //-------------------------------------------------------------------------
  boolean get8segmentEncoder(){
     _8segmentEncoder = (digitalReadDirect(encoder0PinC)==HIGH);
     return _8segmentEncoder;
  }

  //-------------------------------------------------------------------------
  
  void calculateDirection(){
    lastDirectionEncoders = directionEncoders;
    directionEncoders = 0;
    
    if(digitalReadDirect(encoder0PinA)== HIGH){ directionEncoders += 1;}
    else{ directionEncoders += 0;}
    if(digitalReadDirect(encoder0PinB)== HIGH){ directionEncoders +=3;}
    else{ directionEncoders +=5;}
    
    //last_8segmentEncoder = _8segmentEncoder;
    //_8segmentEncoder = (digitalRead(encoder0PinC)==HIGH);
  }

  
  //-------------------------------------------------------------------------
  // Use called by attachInterrupt(encoder0PinA, encoderChange, CHANGE);
  void loopAttachInterrupt(){  
    calculateDirection();
    if(lastDirectionEncoders!=directionEncoders){
      if(lastDirectionEncoders==OFF_ON || directionEncoders==ON_OFF){
        headDirection =-1;
        encoder1Pos-=1;
        if(encoder1Pos<0){
          encoder1Pos=0;
        }
        stitch = (encoder1Pos)-28;
      }
      else if(lastDirectionEncoders==ON_ON || directionEncoders==OFF_OFF){
        headDirection =1;
        encoder1Pos+=1;
        if(encoder1Pos>255){
          encoder1Pos=255;
        }
        stitch = (encoder1Pos)-28;
      }
    }
    lastDirectionEncoders = directionEncoders;
  }
};
#endif

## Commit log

2012-10-20 add arduino code
2012-10-22 add prototype in processing for app
2012-10-23 fix connected status to arduino
    [protoAppKnitic_p5.pde, serial_comunication.pde]
2012-10-23 fixed serial connection detection
    [protoAppKnitic_p5.pde, serial_comunication.pde]
2012-10-23 arduino code update
2012-10-23 fix direction sensor with encoders
2012-10-23 fix absolute position encoders
2012-10-23 commend unnecesary serial prints
2012-10-24 timer in sender
2012-10-24 started figuring out arduino serial receive
2012-10-25 small changes to make arduino serial receive work
2012-10-27 code cleanup: removed a serial.print and cleanup up some comments
2012-10-28 fix back to front knitting
    [protoAppKnitic_p5.pde]
2012-10-29 trying to get cart position from encoder readings
2012-10-29 added code to receive stitch value from arduino/serial
2012-10-29 removed unecessary print
2012-10-29 trying to fix encoder reading values
2012-10-29 still trying to fix encoder reading values... taking care of end cases...
2012-10-29 trying to get rid of crashes on quit. this seems to be one problem
    [serial_comunication.pde]
2012-10-30 encoders change 4 times per needle. hacks to account for that.
2012-11-02 add visualization 16 current stitch
2012-11-04 fix solenoids display
2012-11-05 take out some anoying print
2012-11-07 add new update method for solenoids per knitch by knitch
2012-11-07 renaming variables selenoids to Solenoids - some spelling mistakes
    [drawElements.pde, protoAppKnitic_p5.pde, serial_comunication.pde]
2012-11-21 fix movement heads left right with 32 offset
    [buttons_actions.pde, drawElements.pde, editImage.pde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]
2012-11-21 trying to fix comunication between arduino and processing, Processing misses some messages.
    [buttons_actions.pde, protoAppKnitic_p5.pde, serial_comunication.pde]
2012-11-22 fix spelling mistake with selenoids to solenoids
2013-03-07 fix mapping solenoids
2013-03-09 fix left and right direction label
    [drawElements.pde, protoAppKnitic_p5.pde, serial_comunication.pde]
2013-03-09 fix array solenoids
2013-03-09 fix 16 solenoid visualization
    [drawElements.pde, protoAppKnitic_p5.pde]
2013-03-11 fix 16 solenoid visual selector. Add color to direction
    [drawElements.pde, protoAppKnitic_p5.pde]
2013-03-14 fix left and right direction to apply pattern to solenoids. Also simplify code
    [drawElements.pde, protoAppKnitic_p5.pde]
2013-03-17 fix hotplugging usb, left placing pattern, mirror pattern, handling big patterns, handling small with patterns
    [buttons_actions.pde, drawElements.pde, protoAppKnitic_p5.pde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]
2013-03-18 clear code, add nicer font,fix edit pixels
    [buttons_actions.pde, drawElements.pde, editImage.pde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]
2013-03-18 fix hoting solenoids, and warning when head is left in middle
    [buttons_actions.pde, drawElements.pde, protoAppKnitic_p5.pde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]
2013-03-28 add PCB design
    [KniticV1_pcb.fzz, KniticV2_PCB.fzz]
2013-03-29 Handle encoders with a state machine
    Differences between the old and new encoder methods:
    Old code used string compares, New code uses an arrary lookup
    Old code:
    1. Tracked each change in the encoder signals
    as a movement in a direction
    2. Accepted two movements in the same direction as
    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
2013-04-01 add comunication improved with 2char bit encoded the 16 solenoids
2013-04-01 clean code and fix serial send
    [buttons_actions.pde, drawElements.pde, keyEvents.pde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]
2013-04-01 add new more efficient encoder code not using strings instead shorts
    [openKnitting_handMadepcb_v0_1.ino]
2013-04-01 deleting arduino_code/openKnitting_handMadepcb_v0_1/openKnitting_handMadepcb_v0_1.pde
2013-04-04 fix odd small patterns
    [buttons_actions.pde]
2013-04-19 add current stich selection and visualization. It is a important new step.
2013-05-03 new PCB design for ArduinoDue
    [KniticV2_+CompactPCB2Res.fzz]
2013-05-03 jpg from PCB design
2013-05-07 chech encoderC
2014-01-06 1layer PCB design. missing custom-made power connector
    [KniticV2_PCBmillingGND1Layer.fzz]
2014-01-15 buttons bigger
2014-03-02 Add feature double bed - two Colours
    Exported new app for macox windows soon
2014-03-03 fix test send line test
    fix test_send line to correct speed serial to 115200
    [test_solenoids_SendHoleLine.pde]
2014-05-10 new pcb with jumper
    This redesign by Lucas Bahle and Kanno So. This one can alternative
    power from Vin of Arduino solenoids.
    [KniticV201_+CompactPCB2Res.fzz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]
2015-08-10 test endlines to calibrate
2015-08-11 add test to detect belt shift
    if this works rest works like charm
2015-08-11 add console for belt shift
2015-08-11 belt shift change
2015-09-09 sdrop bug
    doesn't support by processing 3.0
    [buttons_actions.pde, protoAppKnitic_p5.pde]
2015-09-10 finish to change scrollable list usage
    clean all error and malfonction of scrollable list
    [buttons_actions.pde, parametricSweater.pde, protoAppKnitic_p5.pde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]
2015-09-10 Compatibilitie with Mega and Uno interrupt
    change the interupt fonction
2015-09-11 add new version of pcb design in eagle
    new pcb and breakout board for the kh-970
    [knitic sol connect kh970.brd, knitic sol connect kh970.sch, knitic v2.1.brd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]
2015-09-13 Add info and reset/led on pcb design
    [knitic sol connect kh970.brd, knitic sol connect kh970.sch, knitic v2.1.brd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]
2015-09-14 end line for more compatibilities
    changing filter value
2015-09-16 add refresh usb list button
2015-09-16 try to understand the error in pixel
    [encoders.h, protoAppKnitic_p5.pde, serial_comunication.pde]
2015-09-17 clean and error pixel solution search
    [openKnitting_handMadepcb_v0_1.ino]
2015-09-17 no more error in pixel
    fixe the error in pixel, try to access inexistante position on the array
    : pixelArray
    [buttons_actions.pde, protoAppKnitic_p5.pde, serial_comunication.pde]
2015-09-17 Fix error on corrupt data
    If you send and recieve the data inside the interrupt it is only when
    you move so more interrupt and corrupt data for the future
    if it is outside the interrupt that can be do when you don't move
    [openKnitting_handMadepcb_v0_1.ino]
2015-09-18 Clean and new solenoid test
    some clean of old code, new solenoid test to check one by one
2015-09-20 fix beltshift
2015-09-20 Filter values need to be regulated in each machine
    Added instructions
2015-09-20 fix last commit preprocessors position
    [openKnitting_handMadepcb_v0_1.ino]
2015-09-21 lots of clean in arduino, solenoids close to be fix
    - merge the fork of kinasmith to fix the solenoid glitch, close to the
    solution!!
    - clean all the unused variable and use more the defined_knitic.
    - delete the zip source to less weight
    [defined_knitic.h, encoders.h, openKnitting_handMadepcb_v0_1.ino]
2015-09-21 clean end and export windows-linux
    clean end of all arduino and processing part
    export executable except macos because i can't
2015-09-25 control transfert, release solenoids, less glitch
    - control transfert to detect corrupt data
    - release solenoids when no connection
    - less glitch at the extremity
    [openKnitting_handMadepcb_v0_1.ino, serial_comunication.pde]
2015-09-25 Add a port.clear() before receive check of the pixels
    This avoid many double checks
    [serial_comunication.pde]
